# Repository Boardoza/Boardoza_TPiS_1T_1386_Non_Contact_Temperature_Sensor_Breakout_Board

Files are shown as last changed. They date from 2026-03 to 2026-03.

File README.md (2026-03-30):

# Boardoza TPiS 1T 1386 L5.5 H Thermopile Sensor Breakout Board

The **Boardoza TPiS 1T 1386 L5.5 H Breakout Board** is a non-contact infrared temperature sensor board designed for makers, developers, and embedded system enthusiasts who need accurate temperature measurements without physical contact. It uses the **Excelitas TPiS 1T 1386 L5.5 H** thermopile sensor to measure object temperature in a fast, hygienic, and contactless way, making it ideal for projects where traditional contact sensors are not suitable.

The onboard sensor provides strong thermal stabilization, ensuring reliable and consistent measurements even under harsh or changing environmental conditions. Communication is handled via the **I²C interface**, allowing easy integration with popular development platforms such as Arduino, ESP32, and Raspberry Pi. This breakout board is well suited for **maker projects and prototypes including non-contact thermometers, industrial temperature monitoring, HVAC systems, smart home applications, medical devices, and general IoT-based temperature sensing solutions**.

## [Click here to purchase!](https://www.ozdisan.com/p/gelistirme-kitleri-ve-aksesuarlari-617/boardoza-tpis-1t-1386-1202719)
| Front Side | Back Side |
|:---:|:---:|
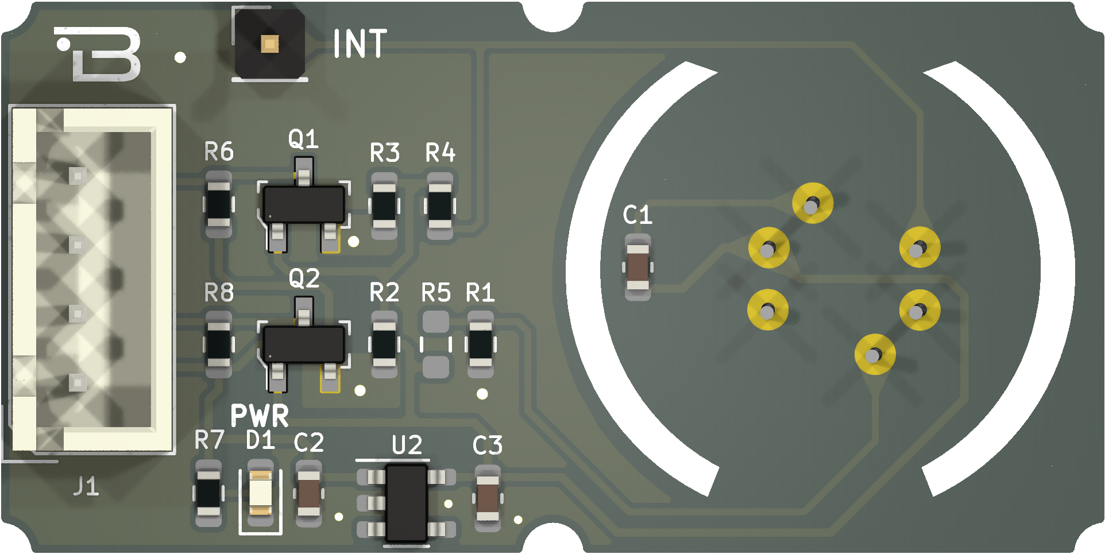
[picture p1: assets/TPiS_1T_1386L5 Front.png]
TPiS 1T 1386 Front
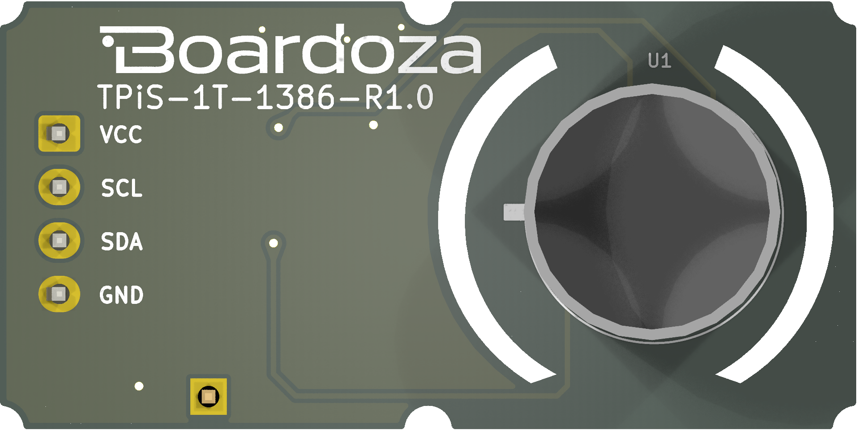
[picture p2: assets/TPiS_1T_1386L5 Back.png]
TPiS 1T 1386 Back
|  |  |

---

## Key Features

- **Non-Contact Temperature Measurement:** Measures object temperature without physical contact using infrared sensing technology.
- **Excelitas Thermopile Sensor:** Equipped with the **TPiS 1T 1386 L5.5 H** medical-grade thermopile sensor.
- **Thermal Stabilization:** Delivers stable and reliable temperature readings even in harsh or changing environmental conditions.
- **I²C Communication Interface:** Standard I²C protocol for easy integration with microcontrollers and development boards.
- **Wide Supply Voltage Support:** Compatible with both **3.3V and 5V** systems.
- **Interrupt Output:** Open-drain, active-low interrupt pin for event-based temperature monitoring.

---

## Technical Specifications

**Model:** TPiS 1T 1386 L5.5 H  
**Manufacturer:** Boardoza  
**Manufacturer IC:** Excelitas Technologies  
**Supply Voltage:** 3.3V - 5V  
**Functions:** Non-contact infrared temperature sensor  
**Communication Interface:** I²C  
**I²C Clock Speed:** Up to 400 kHz (clock stretching supported)  
**Interrupt Output:** Open-drain, active-low  
**Maximum Current per Pin:** −100 mA to +100 mA  
**Storage Temperature:** −40 °C to +105 °C  
**Operating Temperature:** −20 °C to +105 °C  
**Board Dimensions:** 20 mm × 40 mm

---

## Board Pinout

### ( J1 ) I²C & Power Connector

| Pin Number | Pin Name | Description |
|:---:|:---:|---|
| 1 | VCC | Power supply input (3.3V - 5V) |
| 2 | SCL | I²C serial clock line |
| 3 | SDA | I²C bidirectional data line |
| 4 | GND | Ground |

### ( J2 ) Interrupt Connector

| Pin Number | Pin Name | Description |
|:---:|:---:|---|
| 1 | INT | Open-drain, active-low interrupt output. Cleared by reading sensor registers |

---

## Board Dimensions

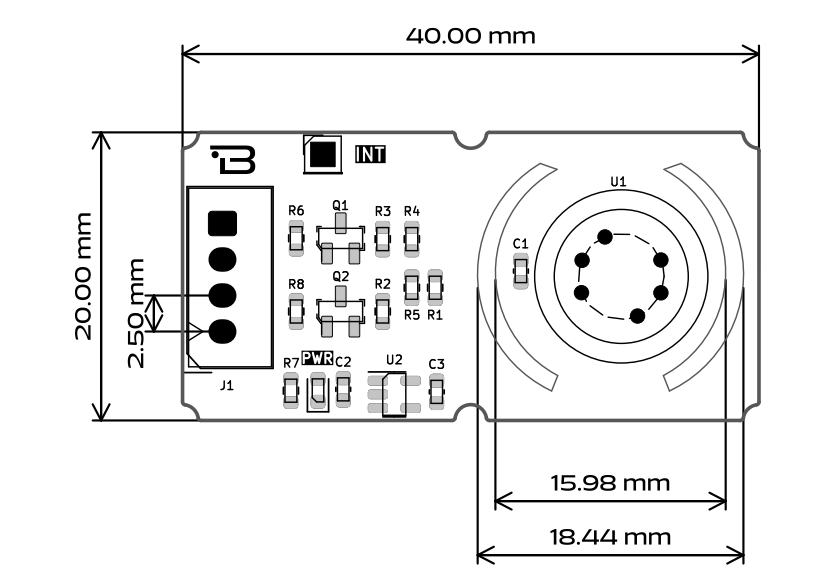
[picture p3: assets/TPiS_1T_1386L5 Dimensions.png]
Board Dimensions


---

## Step Files

[Boardoza TPiS_1T_1386L5.step](./assets/TPiS_1T_1386L5%20Step.step)

---

## Datasheet

[TPiS 1T 1386 L5.5 H Datasheet.pdf](./assets/TPiS_1T_1386L5%20Datasheet.pdf)

---

## Version History

- V1.0.0 – Initial Release

---

## Support

- If you have any questions or need support, please contact **support@boardoza.com**

---

## **License**

This repository contains both hardware and software components:

### **Hardware Design**

[][cc-by-sa]

All hardware design files are licensed under [Creative Commons Attribution-ShareAlike 4.0 International License][cc-by-sa].

[cc-by-sa]: http://creativecommons.org/licenses/by-sa/4.0/
[cc-by-sa-shield]: https://img.shields.io/badge/License-CC%20BY--SA%204.0-lightgrey.svg

### **Software/Firmware**

[][bsd]

All software and firmware are licensed under [BSD 3-Clause License][bsd].

[bsd]: https://opensource.org/licenses/BSD-3-Clause
[bsd-shield]: https://img.shields.io/badge/License-BSD%203--Clause-blue.svg

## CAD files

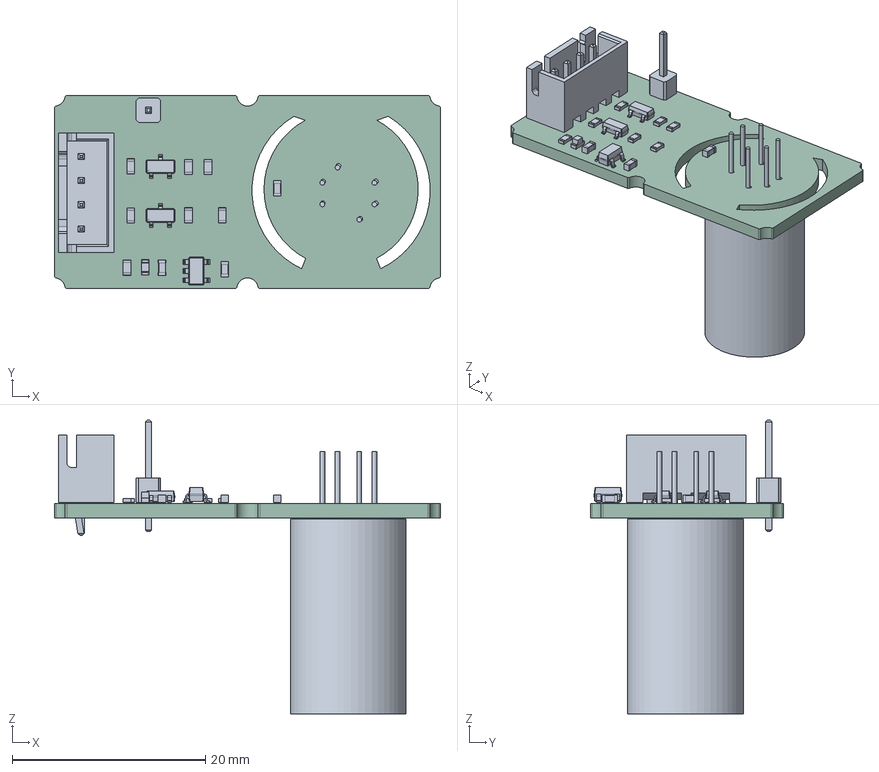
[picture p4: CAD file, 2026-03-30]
assets/TPiS_1T_1386L5 Step.step
40.0 x 20.0 x 30.4 mm
R_0603_1608Metric x 7
SOT-23-5
C_0603_1608Metric x 3
SOT-23 x 2
PinHeader_1x01_P2.54mm_Vertical
JST_XH_B4B-XH-A_1x04_P2.50mm_Vertical
LED_0603_1608Metric
TpÄ±s 1t v2.1
kibot_2zmiddj3_PCB

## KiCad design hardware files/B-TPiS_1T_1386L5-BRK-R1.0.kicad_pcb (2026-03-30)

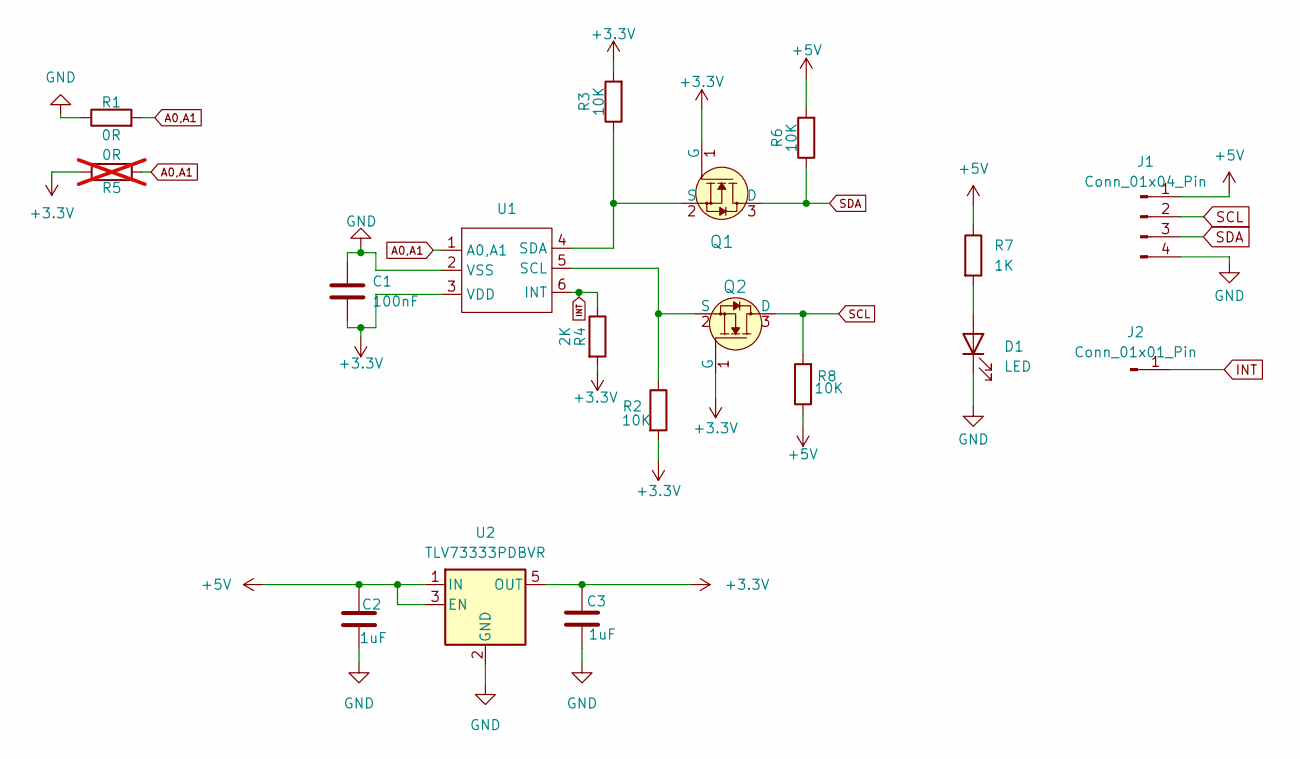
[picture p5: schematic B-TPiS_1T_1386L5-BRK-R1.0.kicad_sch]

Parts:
C1: 100nF; C_0603_1608Metric; MPN CL10B104KB8NNNC
C2, C3: 1uF; C_0603_1608Metric; MPN CL10A105KO8NNNC
D1: LED; LED_0603_1608Metric; MPN LTST-C190KRKT
J1: Conn_01x04_Pin; 2317-04S_1x04_P2.50mm_Vertical
J2: Conn_01x01_Pin; PinHeader_1x01_P2.54mm_Vertical
Q1, Q2: 2N7002-7-F; SOT-23-3; MPN 2N7002_R1_00001; Digi-Key_PN 2N7002-FDICT-ND
R1: 0R; R_0603_1608Metric; MPN CRT03J7-R0R0
R2, R3, R6, R8: 10K; R_0603_1608Metric; MPN 0603WGJ0103T5E
R4: 2K; R_0603_1608Metric; MPN 0603SAJ0202T5E
R5: 0R; R_0603_1608Metric; MPN CRT03J7-R0R0; not fitted
R7: 1K; R_0603_1608Metric; MPN CRT03J7E1001
U1: TPiS 1T 1386
U2: TLV73333PDBVR; SOT-23-5

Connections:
+3.3V: C1.2, C3.1, Q1.1 (G), Q2.1 (G), R2.2, R3.2, R4.2, R5.2, U1.3 (VDD), U2.5 (OUT)
+5V: C2.1, J1.1, R6.2, R7.1, R8.1, U2.1 (IN), U2.3 (EN)
A0,A1: R1.2, R5.1, U1.1 (A0,A1)
GND: C1.1, C2.2, C3.2, D1.1 (K), J1.4, R1.1, U1.2 (VSS), U2.2 (GND)
INT: J2.1, R4.1, U1.6 (INT)
unnamed: D1.2 (A), R7.2
unnamed: Q1.2 (S), R3.1, U1.4 (SDA)
unnamed: Q2.2 (S), R2.1, U1.5 (SCL)
SCL: J1.2, Q2.3 (D), R8.2
SDA: J1.3, Q1.3 (D), R6.1

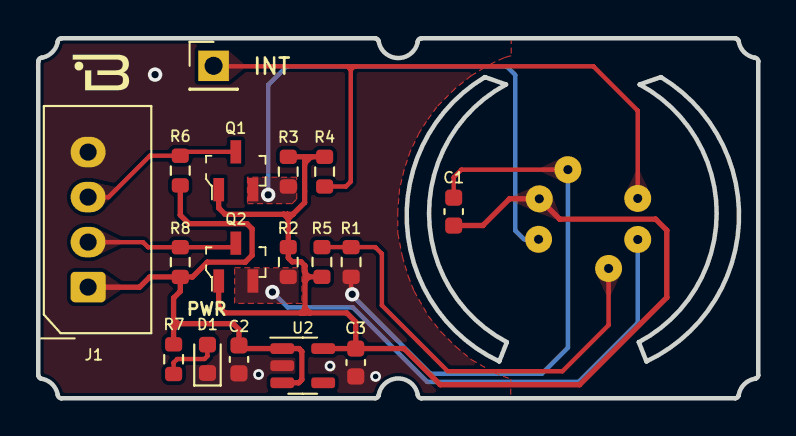
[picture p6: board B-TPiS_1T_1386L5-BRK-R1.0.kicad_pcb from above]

Board: 2 copper layers, 40.0 x 20.0 mm, 18 parts (1 on the bottom side), 10 nets.

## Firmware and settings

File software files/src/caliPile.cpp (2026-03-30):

#include "caliPile.h"

/**
 * @brief Constructor for the caliPile class.
 * 
 * This constructor initializes an instance of the caliPile class.
 * 
 * @param intPin Pin number to be used as the interrupt pin. 
 *               This pin will be configured as an input pin.
 */
//#define TPIS_1S
#define TPIS_1T

#ifdef TPIS_1S
float lookUpNumber = (float) 3.8f; 
#endif
#ifdef TPIS_1T
float lookUpNumber = (float) 4.2f;
#endif

bool newInt = false;

/**
 * @brief Constructor for the caliPile class.
 * 
 * Initializes the caliPile object with the specified interrupt pin.
 * 
 * @param intPin The interrupt pin to be used for the caliPile object.
 */
caliPile::caliPile(uint8_t intPin) {
    pinMode(intPin, INPUT);
    interruptPin = intPin;
}

/**
 * @brief Activates the sensor by sending the call and reload command.
 * 
 * This function activates the sensor by sending the call and reload command.
 * It writes the appropriate values to the registers and introduces a delay
 * to allow the sensor to initialize.
 * 
 * @note This function assumes that the necessary registers have been properly configured before calling it.
 *       It is important to ensure that the appropriate register settings are applied before activating the sensor.
 */
void caliPile::activateSensor() {
    writeRegister(0x00, 0x04, 0x00); // Call and reload command
    delay(10);
}

uint8_t caliPile::interruptStatus() {
    uint8_t tempValue = readRegister(SENSOR_ADDRESS, INTERRUPT_STATUS);
    return tempValue;
}

/**
 * @brief Initializes the motion detection settings of the sensor.
 * 
 * This function initializes the motion detection settings of the sensor by
 * configuring the necessary registers with the provided parameters.
 * It sets the LPTime1 and LPTime2 values, selects the temperature source,
 * configures the cycle time, and sets the presence and motion thresholds.
 * 
 * @param LPTime1 The value for LPTime1 register. Determines the low power time duration.
 * @param LPTime2 The value for LPTime2 register. Determines the low power time duration.
 * @param tempSource The temperature source selection value for the SRC_SELECT register.
 * @param cycleTime The cycle time value for the SRC_SELECT register. Determines the measurement cycle time.
 */
void caliPile::initMotion(uint8_t LPTime1, uint8_t LPTime2, uint8_t tempSource, uint8_t cycleTime) {
    writeRegister(SENSOR_ADDRESS, INT_MASK, 0x1C);
    writeRegister(SENSOR_ADDRESS, SLP12, LPTime2 << 4 | LPTime1);
    uint8_t temp = readRegister(SENSOR_ADDRESS, SRC_SELECT); 
    writeRegister(SENSOR_ADDRESS, SRC_SELECT, temp | tempSource << 2 | cycleTime);
    writeRegister(SENSOR_ADDRESS, TP_PRES_THLD, 0x22); // presence threshold
    writeRegister(SENSOR_ADDRESS, TP_MOT_THLD, 0x0A); // motion threshold
}

/**
 * @brief Perform temperature calculations based on sensor EEPROM data.
 * 
 * This function reads EEPROM data from the sensor, performs temperature calculations using the data,
 * and calculates the value of 'k' based on the formula provided.
 */
void caliPile::TempCalculations() {
    writeRegister(SENSOR_ADDRESS, EEPROM_CONTROL, 0x80);
    readRegisters(SENSOR_ADDRESS, EEPROM_PTAT25, 2, &tempData[0]);
    PTAT25 = ((uint16_t) tempData[0] << 8) | tempData[1];
    readRegisters(SENSOR_ADDRESS, EEPROM_M, 2, &tempData[0]);
    M = ((uint16_t) tempData[0] << 8) | tempData[1];
    M /= 100;
    readRegisters(SENSOR_ADDRESS, EEPROM_U0, 2, &tempData[0]);
    U0 = ((uint16_t) tempData[0] << 8) | tempData[1];
    U0 += 32768;
    readRegisters(SENSOR_ADDRESS, EEPROM_UOUT1, 2, &tempData[0]);
    UOUT1 = ((uint16_t) tempData[0] << 8) | tempData[1];
    UOUT1 *= 2;
    TOBJ1 = readRegister(SENSOR_ADDRESS, EEPROM_TOBJ1);
    readRegisters(SENSOR_ADDRESS, EEPROM_CHECKSUM, 2, &tempData[0]);
    CHECKSUM = ((uint16_t) tempData[0] << 8) | tempData[1];
    writeRegister(SENSOR_ADDRESS, EEPROM_CONTROL, 0x00);

    k = ( (float) (UOUT1 - U0) )/(powf((float)(TOBJ1 + 273.15f), lookUpNumber) - powf(25.0f + 273.15f, lookUpNumber) );

}

/**
 * @brief Initializes the temperature threshold settings of the sensor.
 * 
 * This function initializes the temperature threshold settings of the sensor
 * by configuring the necessary registers with the provided threshold value.
 * It writes the threshold value to the TPOT_THR register, sets the higher byte
 * to 0x00, sets the temperature source selection bit, and reads the threshold 
 * value back from the sensor registers.
 * 
 * @param Tcounts The threshold value to be set in the TPOT_THR register.
 */
void caliPile::initTPotThreshHold(uint16_t Tcounts) {
    uint8_t rawData[2] = {0, 0};
    writeRegister(SENSOR_ADDRESS, TPOT_THR, Tcounts);
    writeRegister(SENSOR_ADDRESS, (TPOT_THR + 1), 0x00);
    uint8_t temp = readRegister(SENSOR_ADDRESS, SRC_SELECT);
    writeRegister(SENSOR_ADDRESS, SRC_SELECT, temp | 0x10);
    readRegisters(SENSOR_ADDRESS, TPOT_THR, 2, &rawData[0]);
    uint16_t TPOTTHR = ((uint16_t) rawData[0] << 8) | rawData[1];
}

/**
 * @brief Initializes the temperature motion threshold value in the sensor.
 * 
 * This function sets the temperature motion threshold value in the sensor to the specified Tcounts.
 * 
 * @param Tcounts The temperature motion threshold value to be set in the sensor.
 */
void caliPile::initTpMotionThreshHold(uint16_t Tcounts) {
    writeRegister(SENSOR_ADDRESS, TP_MOT_THLD, Tcounts);
}

/**
 * @brief Initializes the temperaturepresence threshold value in the sensor.
 * 
 * This function sets the temperature presence threshold value in the sensor to the specified Tcounts.
 * 
 * @param Tcounts The temperature presence threshold value to be set in the sensor.
 */
void caliPile::initTpPresenceThreshHold(uint16_t Tcounts) {
    writeRegister(SENSOR_ADDRESS, TP_PRES_THLD, Tcounts);
}

/**
 * @brief Get the ambient temperature from the sensor.
 * 
 * This function reads the ambient temperature data from the sensor, processes it, and returns the ambient temperature value.
 * 
 * @return The ambient temperature value obtained from the sensor in degrees Celsius.
 * 
 * @details
 * The ambient temperature value is read from the sensor register TPAMBIENT and processed to obtain the actual temperature value.
 * The temperature value is returned as a floating-point value in degrees Celsius.
 */
float caliPile::getAmbientTemp() {
    uint8_t rawData[2] = {0, 0};
    readRegisters(SENSOR_ADDRESS, TPAMBIENT, 2, &rawData[0]);
    uint16_t TPAmbient = ((uint16_t)(rawData[0] & 0x7F) << 8) | rawData[1];
 
    return TPAmbient;
}
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

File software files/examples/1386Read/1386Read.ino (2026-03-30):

#include "caliPile.h"

const int interruptPin = 4;
uint8_t  intStatus = 0;
bool presSign = false, motSign = false;
caliPile sensor(interruptPin);

void inthandler() {
  newInt = true;
}

void setup() {
  Serial.begin(115200);

  Wire.begin();

  sensor.activateSensor();

  sensor.initMotion(LP_8s, LP_1s, src_TPOBJLP1_TPOBJLP2, ms30);

  sensor.TempCalculations();
  sensor.initTPotThreshHold(131); //0x83

  sensor.initTpMotionThreshHold(10);

  sensor.initTpPresenceThreshHold(30);
  attachInterrupt(digitalPinToInterrupt(interruptPin), inthandler, FALLING);  // define interrupt for INT pin output of CaliPile
}

void loop() {

  Serial.print(sensor.calcAmbientTemp(sensor.getAmbientTemp()));
  Serial.print("  ");
  Serial.print(sensor.calcObjectTemp(sensor.getObjectTemp(), sensor.calcAmbientTemp(sensor.getAmbientTemp())));
  Serial.println("  ");
  delay(100);
}

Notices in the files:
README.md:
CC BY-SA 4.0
